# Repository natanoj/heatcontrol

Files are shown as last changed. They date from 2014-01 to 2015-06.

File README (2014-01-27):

This repository contains documentation in the form of schematics, pcb
design files and text documents describing the design, implementation
and testing of a system for home automation as well as software needed
to run on the hardware. The primary goal for the system is home heat
regulation, but it is not limited to that.

The fundamental requirements for this project is for communication to
be carried over IP, preferably IPv6, over Ethernet. See the
./doc/report for details.

System software will be based on the Contiki OS, see the submodule
./software/contiki

Design software used
====================
The goal is to only use open source software programs in this project.
The hardware design is created using software from the gEDA project,
see http://www.geda-project.org/ with electronic simulation using the
Gnucap simulator, see http://www.gnucap.org . Schematics are created
using gschem 1.6 and 1.8.

Directory structure
===================
./doc/report a report for the system, including design calculations
./schem      schematics
./pcb        PCB layouts
./software   software running on or communicates with the system

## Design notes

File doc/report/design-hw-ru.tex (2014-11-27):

% Copyright Jonatan Åkerlind 2012
% design process of the room unit

\subsubsection{Component selection}
The unit should present a few parameters to the user and also be able
to react on user input. For this requirement a simple LCD and a few
push buttons is sufficient. A simple two row LCD with integrated
driver, the Newhaven Display NHD-C0220BIZ-FS(RGB) with integrated RGB
backlight, is selected. For the push buttons debounce an MCU is
used. This MCU will also be used to drive the RGB backlight diodes
using PWM to control the color and brightness. The Atmel ATtiny24A is
chosen since it has three PWM output channels and enough I/O to
support the push buttons.

Communications by Ethernet need connector, magnetic components for
electrical isolation and an Ethernet interface circuit. The MAG45
Ethernet jack with integrated magnetic, LED and PoE diode components
is chosen to simplify design effort and minimize board size. For the
driver circuit the Micrel KSZ8851 is selected due to price and simple
SPI interface. For Power over Ethernet operations a DC-DC converter
transformer with a PWM driver and a PoE driver circuit is needed. The
Texas Instruments TPS23757 is selected as the driver circuit since it
has both PoE and DC-DC PWM converter driving interfaces. Würth
eletronics has several options for ready-made flyback DC-DC PWM
transformers with PoE level input, auxilary output for driving the PWM
circuit matching the TPS23757 and output options for wanted Vdd
voltage.

As environment sensors the Microchip TC1046 is chosen as the
temperature sensor due to price as well as being pre-calibrated. The
Honeywell HIH-5031 is chosen as the relative humidity sensor since it
has a very simple linear voltage output which will simplify the sensor
interface design process. An optional pyrolytic infrared (PIR) sensor
can be used to detect human presence in the room that is
regulated. The Zilog ZMOTION Detection Module II is chosen for
simplicity since the module is ready to use with a simple serial
interface and the relatively small form factor.

The Atmel ATmega1284P is chosen as the MCU since it has I/O that will
support SPI interface for the Ethernet controller and TWI interface
for the display and ATtiny24A, AD converters for temperature and
humidity sensors. Four interrupt inputs are used for pushbutton
events, ethernet data events, ethernet power management events (Wake
on LAN) and PIR signal events.

All resistors are chosen from the E48 series.

\subsubsection{Power budget}
Power budget for all components except the PSU components can be seen
in \tabref{tab:powerbudget_roomunit}. All components can or need to be
driven by 3.3 V which therefore is selected as the overall system
voltage, $V_{DD}$. The total maximum power budget for the design is
seen in the table as approximately 140 mA. For the power supply output
stage a maximum current of 250 mA and a minimum of 100 mA is chosen.

\begin{table}
\begin{tabular}{|l|l|l|l|}
\hline
Reference designator & Name        & Typical current & Max current\\
\hline
U100                 & TC1046      & 35 $\mu$A        & 60 $\mu$A\\
U101                 & HIH-5031    & 200 $\mu$A       & 500 $\mu$A\\
A100                 & ZDM II      & $<$ 8.9 mA          & 8.9 mA\\
U200                 & NHD-C0220BIZ-FS & 1 mA         & 1 mA ? \\
U200 (LED)           & NHD-C0220BIZ-FS(RGB) & $<$ 44 mA  & 44 mA \\
U201                 & ATtiny24A   & 210 $\mu$A       & 210 $\mu$A ? \\
U301                 & KSZ8851     & 85 mA            & 85 mA ? \\
U400                 & ATMega1284P & 0.4 mA           & 0.4 mA ? \\
D552                 & LGQ971      & 20 mA            & 20 mA \\
\hline
Total                &             & $<$ 160 mA            & 160 mA \\
\hline
\end{tabular}
\caption{Power budget for room unit 3.3 V components}
\label{tab:powerbudget_roomunit}
\end{table}

\subsubsection{PoE converter}
According to the power budget summary
in \tabref{tab:powerbudget_roomunit} and the previous section the
maximum power drawn is approximately 330 mW. This is without the power
consumed by the DC/DC converter itself (TPS23757). According to the
PoE standard there are different classifications based upon maximum
average power for a powered device. The lowest power class (Class 1)
specifies a minimum power of 440 mW and a maximum power of 3.84 W. If
the power consumption drops below the minimum the power source
equipment may turn the PoE off and this needs to be verified
carefully. The class is chosen by a classification resistor connected
to the TPS23757 (R501 in the schematics) and should be 243 $\Omega$
for Class 1.

The optional DC adapter interface uses a resistor devider network
(R505, R506) to get the proper voltage at the APD pin of the
TPS23757. This will be designed to be used with a 48 V DC $\pm$10 \%
adapter according to the examples given in Texas Instruments document
SLVA305A. R506 is chosen as 6.8 k$\Omega$ and the minimum startup
voltage is chosen 25 \% below 48 V
% FIXME: reference slva305a properly

\begin{equation}
Vin_{MIN}=48 * 0.75 = 36 \text{ V}
\end{equation}
The ratio between $Vin_{MIN}$ and adapter priority pin typical voltage,
$V_{APDEN}=1.5\text{V}$, is given by
\begin{equation}
DR_{APD}=\frac{Vin_{MIN}}{V_{APDEN}}=\frac{36 \text{ V}}{1.5 \text{ V}}=24
\end{equation}
From here the R505 can be calculated by
\begin{equation}
R505 = R506 * (DR_{APD} - 1) = 156.40 \text{ k$\Omega$}
\end{equation}
R505 is chosen as 158 k$\Omega$. Now the adapter turnon voltage
becomes
\begin{equation}
Vin_{MIN}=\frac{R505+R506}{R506} * V_{APDEN}
= \frac{164.8 \text{ k$\Omega$}}{6.8 \text{ k$\Omega$}} * 1.5 \text{ V}
= 36.353 \text{ V}
\end{equation}
and the adapter turnoff voltage, $V_{ADPTR\_OFF}$, is given by the
minimum adapter priority pin voltage ($V_{APDEN} - V_{APDH}$), where
$V_{APDH}$ is the hysteresis for the APD pin which is 0.31 V
typically.
\begin{equation}
V_{ADPTR\_OFF}=\frac{R505+R506}{R506} * (V_{APDEN} - V_{APDH})
= \frac{164.8 \text{ k$\Omega$}}{6.8 \text{ k$\Omega$}} * 1.2 \text{ V} =
29.082 \text{ V}
\end{equation}
The maximum voltage at the APD pin is, using a 48 V adapter with 10 \% error
\begin{equation}
V_{APD} < \frac{Vin_{MAX}}{\frac{R505+R506}{R506}}
= \frac{48*1.1 \text{ V}}{\frac{164.8 \text{ k$\Omega$}}{6.8 \text{ k$\Omega$}}}
= 2.179 \text{ V}
\end{equation}
which is less than $V_B$ (5 V) and so within the recommended maximum
voltage.

The flyback modulator power stage with feedback network is designed
according to the example given in SLV305A.
% FIXME: reference SLV305A
To minimize the transformer size Discontinous Conduction Mode is
used. With an assumed converter efficiency ($\eta$) of 85 \% and the
given DC voltage transfer ratios according to

\begin{equation}
V_{Imin}=36 \text{ V},
\end{equation}
\begin{equation}
V_{Imax}=57 \text{ V}
\end{equation}
Minimum DC voltage transfer function
\begin{equation}
M_{V DCmin}=\frac{V_O}{V_{Imax}}=\frac{3.3}{57}=0.057895
\end{equation}
and maximum DC voltage transfer function
\begin{equation}
M_{V DCmax}=\frac{V_O}{V_{Imin}}=\frac{3.3}{36}=0.091667
\end{equation}

and assumed duty cycle at DCM/CCM boundary $D_{b max}$=0.3 the minimum
input-output winding ratio of the transformer becomes

\begin{equation}
N_{ps min}=\eta \frac{D_{b max}}{(1-D_{b max})M_{V DCmax}}=3.97
\end{equation}

The PoE transformer (T550) with input (48 V), output (3.3 V and 5 V)
and auxilary (12 V) windings. Prebuilt transformer from TDK part
number EFD15 B82802A0012A315 is chosen, which has 100 $\mu$H input
inductance, 3 $\mu$H leakage inductance at 100 kHz and 1.5 $kV_{AC}$
breakdown between windings. The transformer is specified for input
voltages between 36 - 60 V DC and has a winding ratio (n) between
input and primary output windings of 10. Chosen switching frequency is
200 kHz, to program the TPS23757 to run at 200 kHz a resistor is
connected between the FRS and ARTN pins (R502) with a value given by
\begin{equation}
R502 = \frac{17250}{f_{SW} (kHz)} = \frac{17250}{200} \text{
k$\Omega$} = 86.25 \text{ k$\Omega$}
\end{equation}

A resistor with 86.6 k$\Omega$ resistance is chosen.

To keep the flyback in DCM the maximum magnetizing inductance is
\begin{equation}
L_{m max}=frac{N_{ps}^2 R_{l min} (1-D_{b max})^2}{2
f_{s}}=489 \text{$\mu$ H}
\end{equation}

Which is above the chosen transformer rating.

The switching transistor Q550 and the rectifying diode D551 will be
exposed to voltage and current stresses according the following
calculations.

Minimum and maximum duty cycles
\begin{equation}
D_{min}=M_{V DCmin} \sqrt{\frac{2 f_s L_m}{\eta R_{l min}}}=0.10931
\end{equation}
\begin{equation}
D_{max}=M_{V DCmax} \sqrt{\frac{2 f_s L_m}{\eta R_{l min}}}=0.17308
\end{equation}

%% only for CCM(?)
The peak-to-peak ac current through the magnetizing inductance (input) is
\begin{equation}
\Delta i_{Lm(max)}=\frac{nV_O (1-D_{min})}{f_s L_m}
= \frac{10*3.3*(1-0.10931)}{2*10^5*100*10^{-6}} \text{ A} = 1.4696 \text{ A}
\end{equation}

The current and voltage stresses of the switching transistor and the
rectifying diode are given by
\begin{equation}
I_{SMmax} = \frac{D_{min}V_{Imax}}{f_s L_m} = \frac{0.109*57}{200*10^3*100*10^{-6}} \text{
A} = 0.31154 \text{ A}
\end{equation}
\begin{equation}
I_{DMmax} = nI_{SMmax} = 10*0.31154 \text{ A} = 3.1154 \text{ A}
\end{equation}
\begin{equation}
V_{SMmax} = V_{Imax} +nV_O = 57 + 10*3.3 \text{ V} = 90 \text{ V}
\end{equation}
\begin{equation}
V_{DMmax} = \frac{V_{Imax}}{n} + V_O = \frac{57}{10} + 3.3 \text{ V}
= 9 \text{ V}
\end{equation}
The N-MOSFET IRLM0100TRPbF from International Rectifier can handle
$V_{DSS}=100$ V and $I_D=1.6$ A with a maximum $R_{DS(on)}$ of 220
m$\Omega$ at $V_{GS}=10$ V. Typical gate charge $Q_g=2.5$ nC and
output capacitance $C_O=27$ pF. Multicomp SS54 Schottky diode has a
maximum $I_{DM}=5$ A, maximum reverse voltage $V_{DM}=40$ V and
forward voltage drop $V_F=0.55$ V at 5 A which gives an equivalent
resistance $R_F$ of 0.11 $\Omega$.

Adjusted peak voltage at switching transistor due to transformer leakage
inductance $L_l$, primary $R_p$ and secondary $R_s$ winding
resistances, stray input capacitance $C_p$, and transistor output
capacitance $C_O$. Ringing frequency
\begin{equation}
f_{ring}=\frac{\omega_{ring}}{2\pi}=\frac{1}{\sqrt{L_l(C_O+C_p)}}
\frac{1}{2\pi}=15.106 \text{ MHz}
\end{equation}
characteristic impedance of ringing circuit
\begin{equation}
Z_0=\sqrt{\frac{L_l}{C_O+C_p}}=284.75 \Omega
\end{equation}
ringing voltage spike
\begin{equation}
V_{spike}=I_{SMmax}Z_0=88.711 \text{ V}
\end{equation}
adjusted switching voltage stress
\begin{equation}
V_{SMmax adj}=V_{Imax}+nV_O+V_{spike}=178.71 \text{ V}
\end{equation}
This will be limited with snubber circuit $D_{sn}$ (D553), $R_{sn}$
(R558), and $C_{sn}$ (C555) with $V_{spike new}$ as 5 V.
\begin{equation}
C_{sn(min)}=(\frac{V_{spike}}{V_{spike
new}})^2(C_O+C_p)=11.647 \text{ nF}
\end{equation}
Choosing $C_{sn}$ as 15 nF. Choose $R_{sn}$ for time constant much
larger than switching frequency
\begin{equation}
R_{sn}=\frac{200}{f_s C_{sn}}=66.667 \text{ k$\Omega$}
\end{equation}
Choosing $R_{sn}$ as 64.9 k$\Omega$.
For $D_{sn}$ the MURA120 from ON Semiconductor is chosen, with peak
reverse voltage $V_R$ 200 V and average forward current $I_F$ 1 A.

Maximum input voltage ripple targeted below 1 V gives minimum filter
capacitance
\begin{equation}
C_{in(min)}=\frac{\Delta i_{Lm(max)}D_{max}}{f_s V_{Iripple}}=
1.2718 \mu F
\end{equation}
Choosing $C_{in}$ as one low ESR X7R MLCC 2.2 $\mu$F (C556) and one bulk aluminum
electrolytic at 2.2 $\mu$F (C550).

For the current sense input to the control circuit a resistor,
$R_{CS}$ (R551), is chosen from the primary winding peak current and
max input voltage on $V_{CS}$. According to the datasheet $V_{CSMAX}$
= 0.55 V.

\begin{equation}
R_{cs_{MIN}} = \frac{V_{CSMAX}}{I_{SMmax}} = \frac{0.55}{0.327} =
1.682 \text{$\Omega$}
\end{equation}
$R_{CS}$ is chosen as 1.8 $\Omega$. Maximum power dissipation for this
would then be approx 0.19 W if the peak current was constant. This
corner case is highly unlikely but dimensioning for this case will
keep the design on the safe side. An SMD resistor rated for 250 mW is
chosen.

Output voltage ripple should be below 2 \%
\begin{equation}
V_r=0.02V_O = 0.02*3.3 \text{ V} = 66 \text{ mV}
\end{equation}

% with only one filter capacitor
Equivalent minimum load resistance
\begin{equation}
R_{Lmin}=\frac{V_O}{I_{Omax}} = \frac{3.3}{0.25} \text{ $\Omega$} =
13.2 \text{ $\Omega$}
\end{equation}

Assuming ripple voltage over filter capacitor ESR $V_{rcpp}=27$ mV and
the rest over the filter capacitance $V_{Cpp}=6$ mV gives the maximum
ESR of the filter capacitor
\begin{equation}
r_{Cmax} = \frac{V_{rcpp}}{I_{DMmax}} =
\frac{27}{4.089} \text{ m$\Omega$} = 6.6 \text{ m$\Omega$}
\end{equation}
and the filter capacitance
\begin{equation}
C_{min} = \frac{D_{max}V_O}{f_sR_{Lmin}V_{Cpp}} \text{ F} =
\frac{0.589*3.3}{3*10^5*13.2*6*10^{-3}} = 81.8 \text{ $\mu$F}
\end{equation}

Output voltage set point resistors are calculated using the estimated
integrator zero location at approximately 1 kHz. Integrator zero
capacitors range between 1 nF - 10 nF, 4.7 nF is assumed.
\begin{equation}
R_{IZE} \approx \frac{1}{2* \pi * 4.7 nF * 1 kHz} =
33.9 \text{k$\Omega$}
\end{equation}
\begin{equation}
R_{FBUE} \approx R_{IZE}
\end{equation}
$R_{FBU}$ (R553) chosen as 41.2 \text{k$\Omega$}. $V_{ref}$ = 1.24 V
which then gives $R_{FBL}$ (R554)
\begin{equation}
R_{FBL} = \frac{V_{ref}*R_{FBU}}{V_{out_{NOM}} - V_{ref}}
= \frac{1.24*41.2}{3.3-1.24} = 24.8 \text{k$\Omega$}
\end{equation}
$R_{FBL}$ chosen at 24.3 \text{k$\Omega$} which gives a slightly
higher nominal output voltage. This will compensate a small voltage drop
in the output circuit.

Opto-Isolator, U550, should have a current-transfer-ratio of about
80-160 \% at 5 mA. The Fairchild FOD817A is chosen. At 1-2 mA LED bias
current it has an approximate current-transfer-ratio of 85 \%. Forward
LED voltage $V_{led_{OPTO}}$ at 2 mA is approximately 1.1 V. Bias
current limiting resistor, $R_{OB}$ (R552) calculated at zero duty
cycle
\begin{equation}
V_{led{OPTO_K}} = V_{ref} + 150 mV
\end{equation}
\begin{equation}
R_{OB} = \frac{V_{out_{NOM}} - V_{led_{OPTO}} -
V_{led_{OPTO-K}}}{I_{led_{OPTO}}} = \frac{3.3 - 1.1 - 1.25}{2*10^{-3}}
= 475 \Omega
\end{equation}
The opto-isolator transistor bias current calculated at zero duty
cycle (values from the datasheet of TPS23757). $V_{zdc_{MAX}}$ = 1.7
V, $V_{cs_{MAX}}$ = 0.55 V at $V_B$ = 5 V.
\begin{equation}
V_{ctl_{MAX}} = V_{zdc_{MAX}} + 2*V_{cs_{MAX}}
\end{equation}
\begin{equation}
V_{ctl_{NOM}} = \frac{V_{zdc_{max}} + V_{ctl_{MAX}}}{2} = 2.25 V
\end{equation}
\begin{equation}
R_{CTL} = \frac{V_b - V_{zdc_{MAX}}}{I_{led_{OPTO}}*CTR_{2mA}} =
1.9412 \text{k$\Omega$}
\end{equation}
$R_{CTL}$ (R550) chosen as 2 \text{k$\Omega$}.

% FIXME: do we need secondary side soft start according to SLVA305C 2.8.6 ?

\subsubsection{Peripheral components}
The display needs two capacitors to drive the internal boost converter
for 5 V supply, these are 1 $\mu$F each. The backlight LEDs are
specified according to \tabref{tab:backlightleds} and need serial
resistors with values according to \ref{eq:rledred}, \ref{eq:rledgreen}
and \ref{eq:rledblue}.
\begin{equation}
R_{Red} = \frac{3.3 - 1.9}{17} \text{ k$\Omega$} = 82 \text{ $\Omega$}
\label{eq:rledred}
\end{equation}
\begin{equation}
R_{Green} = \frac{3.3 - 3.0}{17} \text{ k$\Omega$} = 18 \text{ $\Omega$}
\label{eq:rledgreen}
\end{equation}
\begin{equation}
R_{Blue} = \frac{3.3 - 3.0}{10} \text{ k$\Omega$} = 30 \text{ $\Omega$}
\label{eq:rledblue}
\end{equation}

A number of digital nets need pull-up or pull-down resistors, to
minimize leakage currents a typical value of 100 k$\Omega$ is
used. This will only draw 33 $\mu$A when the line is being driven. To
keep external components around the microcontrollers at a minimum the
internal pull-ups are enabled for unused pins and these are left
unconnected. This has the drawback of higher power consumption during
reset condition, but this only occurs either when programming the
microcontroller program memories or when a user presses the reset
button. The latter should however be seen as an exception and will
probably only be used during software development or hardware
verification.

\begin{table}
\begin{tabular}{|l|l|l|}
\hline
Colour & Voltage drop (V) & Current (mA)\\
\hline
Red & 1.9 & 17\\
Green & 3.0 & 17\\
Blue & 3.0 & 10\\
\hline
\end{tabular}
\caption{LCD Backlight LED drive voltages and currents}
\label{tab:backlightleds}
\end{table}

\subsubsection{Mechanical aspects}
The PCBs need to fit in the housing with display, buttons, and PIR
sensor at the proper height. The chosen buttons, Multicomp MCDTS2-4N
12 mm, are 4.3 mm from bottom edge (mounted to PCB) to the button
level. Switch caps, Multicomp KTSC-22, are in total 7.7 mm in height
with a stop surface at 3.5 mm from the bottom. This means that the
casing front inner plane should be at least $4.3+3.5=7.8$ mm from the
top layer of the PCB. The caps have a rounded outer edge at the top
with 1 mm radius and travelling length of 0.5 mm. Assuming a casing
thickness of 2 mm, the casing front inner plane can be at most
$4.3+7.7-1-0.5-2=8.5$ mm from the top layer of the PCB.

The PIR sensor, Panasonic PaPIR EKMC1603113, is in total 20.2 mm from
bottom edge (mounted to PCB) to the top of the lens. The lens is
approximately a half sphere with diameter 22 mm, but edges cut down to
a cylindar with 20.7 mm diameter for mounting in casing. The height
from top of the sphere to the cut edge is given by the circle segment
\begin{equation}
h(2r-h)=\left(\frac{x}{2}\right)^2
\end{equation}
where h is the wanted height, r the radius of the sphere, and x the
segment length. The resulting height is
\begin{equation}
h=\frac{2r}{2}\pm\sqrt{\left(-\frac{2r}{2}\right)^2-\left(\frac{x}{2}\right)^2}=
\begin{cases}
14.725 & >r ~\text{not wanted solution},\\
7.2747 & <r ~\text{wanted solution}.
\end{cases}
\end{equation}

The PIR sensor casing has an edge at 7.3+2 mm from the bottom, which
represents the lowest possible height from top of PCB to inner edge of
casing front.

Combining these dimensions the PIR sensor and the push buttons can be
directly mounted to the PCB with a 2 mm thick casing front at 9.3 mm
from the PCB to inner edge of casing. With the push buttons mounted
closely to the PCB the caps will only protrude $\approx 0.7$ mm,
however the push buttons have 3.5 mm long leads and can therefore be
mounted with a $\approx 1$ mm distance to the PCB surface placing the
switch cap tops at $\approx 1.7$ mm above the casing outer surface.

The EA DOG-M display is 2 mm thick with 7.5 mm long leads at the
bottom for a total length of 9.5 mm from the top surface to the lead
ends. This means that the display needs to be mounted with some
special care. A separate board to mount the display and related
passives and cutting the display leads down to 2.5 mm would leave
approximately $9.3-2-2.5=4.8$ mm between top of PCB to display lead
ends.

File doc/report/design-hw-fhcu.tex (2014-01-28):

% Copyright Jonatan Åkerlind 2012
% design process of the floor heating control unit
Floor heating control unit

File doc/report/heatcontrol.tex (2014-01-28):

\documentclass[a4paper,11pt]{article}
% Copyright Jonatan Åkerlind 2012

% language and character encoding
\usepackage[english]{babel} \usepackage[utf8x]{inputenc}

% nice looking urls
\usepackage{url} \urlstyle{same}

%include eps
\usepackage{graphicx}

% nice code formatting and file referencing
\usepackage{moreverb}

% many nice math functions
\usepackage{amsmath}

% clickable pdf links without borders
\usepackage[pdfborder= 0 0 0]{hyperref}

% needed to access footnote counter for working around
% problems with foontotes in table environments
\usepackage{fmtcount}

% easier referencing of figures, tables and appendices
\newcommand{\figref}[1]{\figurename~\ref{#1}}
\newcommand{\tabref}[1]{\tablename~\ref{#1}}
\newcommand{\appref}[1]{Appendix~\ref{#1}}

\title{Heatcontrol} \author{Jonatan Åkerlind}

\begin{document}

% insert title
\maketitle
\thispagestyle{empty}

\newpage
\begin{abstract}
\setcounter{page}{1}
\noindent{This document describes the specification, planning,
  designing, building and testing of an electronic domestic heat
  control system. The system regulates the temperature in rooms in a
  house by measuring room and outdoor temperature and regulating
  temperature of water based convector heaters as well as water based
  floor heating.}

\end{abstract}

%\thispagestyle{empty}
\newpage

% Table of contents
\tableofcontents

%\thispagestyle{empty}
\newpage

\section{Introduction}
\input{introduction}

\clearpage
\newpage
\section{Specification}
\input{specification}

\clearpage
\newpage
\section{Design}
\input{design}

\clearpage
\newpage
\section{Design verification}
\input{design-verification}

\clearpage
\newpage
\section{Manufacturing}
\input{manufacturing}

\clearpage
\newpage
\section{Product verification}
\input{product-verification}

\clearpage
\newpage
\section{Conclusions}
\input{conclusions}

\clearpage
\newpage
\input{references}

\clearpage
\newpage
%\input{appendix}

\end{document}

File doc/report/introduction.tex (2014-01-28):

% Copyright Jonatan Åkerlind 2012
This document will describe the design and implementation of a heat
control system for water based domestic heating applications.

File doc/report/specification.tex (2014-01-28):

% -*- Mode: latex; Mode: auto-fill -*-
% Copyright Jonatan Åkerlind 2012
The system should regulate the temperature of rooms in a house to
maintain a preset temperature and at the same time be conservative
with available energy. Temperature preset should be adjustable for
each room in a simple way from the rooms. Further the system should
have a way to set different temperatures during different time ranges
of one day, i.e. to lower the room temperature during night or when
the room is unused.

Another functionality of the system should be the ability of measuring
warm water temperature and controlling warm water circulation. The
temperature should be measured where the warm water circulation end
point is located, i.e. in the house which warm water is delivered
to. When this temperature drops below some preset value the warm water
circulation pump should be activated and run until the temperature
reaches the stored warm water temperature with heat losses calculated
for. 

\subsection{Regulating room temperature}
Room temperature can be controlled by adjusting
heat flow in a water based heating system. Each room will have either
water radiator elements or water based floor heating. The temperature
of the water system can be controlled in a number of ways:
\begin{itemize}
\item{Adjusting the temperature of water flowing in to the radiators
  and floor heating. These two systems can have individual water
  temperatures\footnote{The temperature of the floor heating water
    cannot exceed the temperature of the water radiators since the
    shunt for the floor heating takes warm water from the radiator
    heat water forward pipe} controlled by motorized shunt
  valves\footnote{The motorized shunt valves will have end limit
    switches, normally open non-potential contacts, indicating max or
    min setting}.}
\item{Controlling water flow in the floor heating system for each
  room. Water flow is controlled by electromagnetic valves which are
  either on or off.}
\item{Controlling water flow in the radiators for each room by turning
  an electromagnetic valve on or off. For systems with thermostats already
  installed there should be an option of indicating to the user if the
  thermostat should be adjusted up or down, i.e. an indirect way of
  controlling water flow in the radiators.}
\item{Circulation pumps for the two different water flows can be
  turned off when the system no longer needs to add heat and likewise
  turned on again for supplying heat.}
\end{itemize}

Heat supply for the system is stored in water accumulators charged by
a system outside the scope of this system, however it should not be
assumed that heat is always available in the accumulators. To reliably
regulate supplied temperature to the water circulation the temperature
of water stored in the accumulators should be measured. 

Input parameters for the regulation needs to be a number of
parameters:
\begin{itemize}
\item{Room temperature for each room.}
\item{Water radiator and floor heating forward and
  return\footnote{The return water temperature can be used to
    calculate total power dissipation for the system.} temperatures.}
\item{Heat water accumulator top and bottom temperatures. This is for
  measuring available energy.}
\item{Outdoor temperature should be used to compensate for energy
  leakage rising with lower outdoor temperatures.}
\end{itemize}
Additionally the system should measure relative air humidity both
outdoor and for each room. This should then be used to both add a
comfort factor, i.e. optionally raise the temperature if it is cold
and humid outside, as well as protect cold rooms from being too
humid. 

\subsection{Heat system interaction}
The interaction with a heater system is to be located at several
different physical locations. One is where the water accumulators are
located, i.e. the energy supply and storage which typically will be a
furnace, solar heater or some kind of heat pump which charges water
accumulators. Another interface is at one or several places where
floor heat water flow is controlled. Both of these types should have
the possibility to control electric shunting valves but only the
latter needs to control regular electric valves.

Regulating electric shunting valves includes checking that the valve
has not reached its end limit in the direction it is being turned. It
also includes measuring the temperature of the regulated water pipe,
which should be measured closely to the shunting valve, as well as the
return water temperature. The unit placed at the location of the water
accumulators needs to be able to measure one outdoor temperature, four
pipe temperatures (water radiator forward and return, accumulator top
and bottom temperatures) and one outdoor air relative humidity. It
also needs to be able to control two circulation pumps, one for warm
water circulation and one for heat water circulation. This heat water
circulation is to be considered a general purpose pump that can be
either heat water circulation over to the house that is to be heated
if the water accumulators are located at another location outside of
the house, or it can be circulation for a separate heater system. In
the first case it should be activated if either of the other
circulation pumps (floor heating or water radiator) are running and in
the second case it should be activated if a room unit for this
separate system requires more heat. In either case it is to be
considered optional.

Floor heating control unit needs to be able to control floor heating
electromagnetic valves for 12 rooms as well as two circulation pumps,
one for the water radiator circulation and one for floor heat
circulation. It should also be able to measure one air temperature and
one air relative humidity as well as the warm water pipe temperature
at the end point of the warm water circulation.

The system should have a standby mode when it should not apply heat
but keep the circulation pumps running for one hour each month. The
shunt valves should also be turned one complete turn from low to high
once each month. This is to keep the pumps and shunt valves from
jamming when the system is unused for a long period of time. All
electromagnetic valves should also be toggled once each month for the
same reason.

\subsection{System interfaces}
Human interaction with the system should be possible in a number of
different ways. In each room the system should display, without the
need to press any buttons or other manual interaction, current room
temperature, wanted room temperature, outdoor temperature and the
current day/night setting. In each room it should also be possible to
see the current room and outdoor relative humidity, however this may
require some manual interaction from the user. The wanted room
temperature as well as day/night setting for that room should be
adjustable from each room in a simple way. Day versus night setting
should be selectable as one of the following; follow the system time
schedule, override as day or night until time schedule changes next
time or override as day or night until user selects another
setting. If using the option of controlling water radiators indirectly
the system must indicate if water radiator thermostats should be
adjusted up or down. The room units controlling floor heating should
also indicate if heat is applied to the room or not.

The unit placed at the location of the water accumulators (the main
unit) should indicate if each output is on or off, if each shunt valve
is regulated up, down or kept at its current setting and display each
input value. It should also show current system day/night setting and
be able to show the day/night time schedule. All system parameters
except individual room temperatures should also be adjustable from
this unit. These are the specified system parameters:
\begin{itemize}
\item{Parameters for the regulation of the forward heat water
  temperatures, i.e. the dependency on outdoor and indoor
  temperatures, outdoor and indoor relative air humidity or manually
  raising or lowering the forward heat water temperature}
\item{Circulation pumps on or off}
\item{Current day or night setting}
\item{Time schedule for day or night setting} 
\item{Warm water circulation high and low temperatures}
\item{System on or standby}
\end{itemize}

Time schedule for day or night setting should have a granularity of 15
minutes, i.e. it should be possible to set a new day or night setting
once every 15 minutes. A finer granularity than this should not be
necessary since the system as a whole is slow; it takes some time to
effectuate a new temperature in a house. 

Floor heat controlling unit should indicate if each output is on or
off, indicate if each shunt valve is regulated up, down or kept at its
current setting and display each input value. It should also show
current system day/night setting. 

There should also be web access to the main unit, i.e. the main unit
should serve HTTP
%% FIXME: reference RFC for HTTP
requests, which should display all system parameters and current input
values. It should also be possible to change the system parameters by
using this HTTP access. Parameters and input values should be
presented in a way that will make it easy to read these parameters
from some other computer system for logging purposes. Optionally the
main unit should have an SNMP
%% FIXME: reference RFC for SNMP
server that will show all parameters and input values and also enable
setting of parameters. Preferably the system should also have an
option to log all or a selection of events to a syslog
%% FIXME: reference RFC for syslog
server.

\subsection{Unit communication}
Communication between the room units and the other units of the system
is to be carried over Internet protocol version 6 (IPv6) or version 4
(IPv4)
%% FIXME: reference RFCs for IPv4 and IPv6
, version should be configurable by the user. IP communication
will be carried over Ethernet
%% FIXME: reference IEEE802.3 for Ethernet
and power supply for the room units
should be Power over Ethernet (PoE)
%% FIXME: reference IEEE802.3af for PoE
. This will then enable the room
units to use a pre-installed Ethernet network in the house that is to
be regulated. Optionally the room units should have power input for
external power supply in case PoE is not available.

Main unit will naturally act as a common communication central for all
other units. All parameters should be sent to the main unit and stored
there in a way that will keep them even if power fails.

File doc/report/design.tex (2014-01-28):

% Copyright Jonatan Åkerlind 2012
The system will consist of hardware, embedded software and optional
software running on a separate computer system for adjusting
parameters and monitoring the system. Each part of the system design
will be described in the following sections.

Design of the hardware components of the system is separated into
different pieces to reduce complexity in the design process. The
following pieces are designed seperately: main control unit, floor
heating control unit and room unit.

\subsection{Hardware: main control unit}
\input{design-hw-mcu}

\subsection{Hardware: floor heating control unit}
\input{design-hw-fhcu}

\subsection{Hardware: room unit}
\input{design-hw-ru}

\subsection{Embedded software}
\input{design-emb-sw}

\subsection{Operator software}
\input{design-oper-sw}

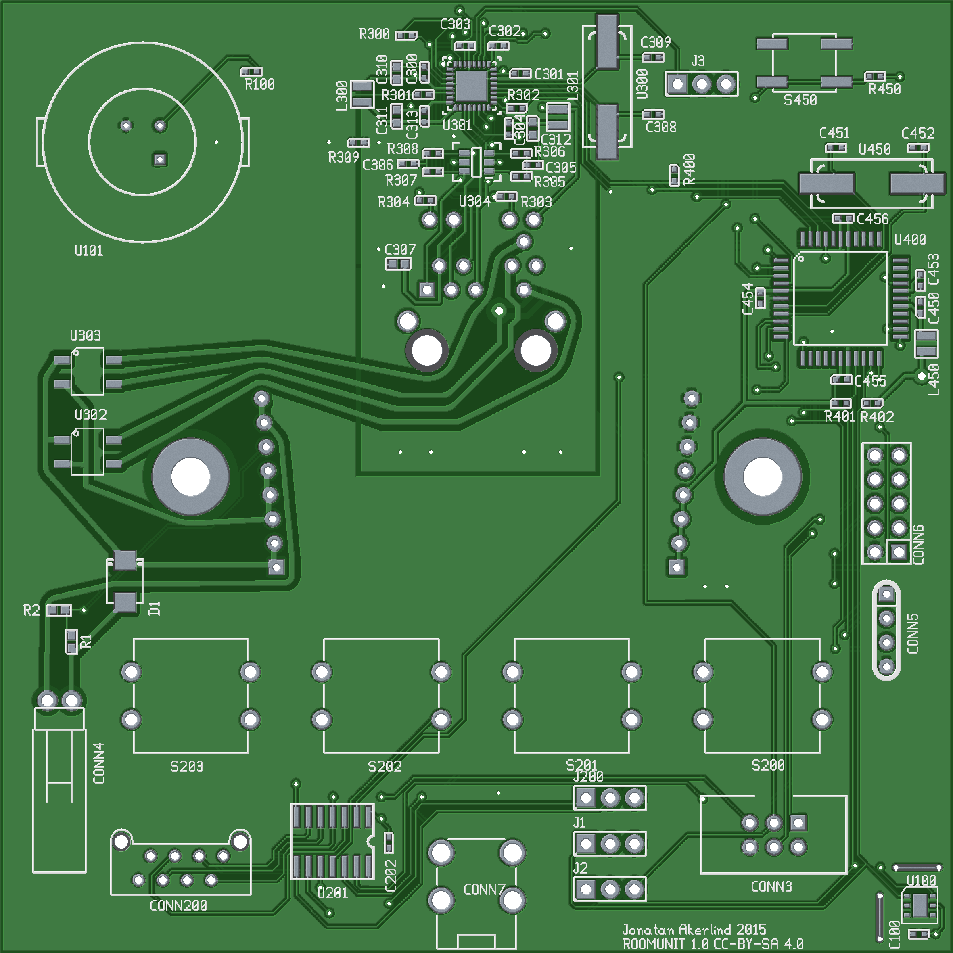
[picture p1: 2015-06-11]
pcb/roomunit.top.png

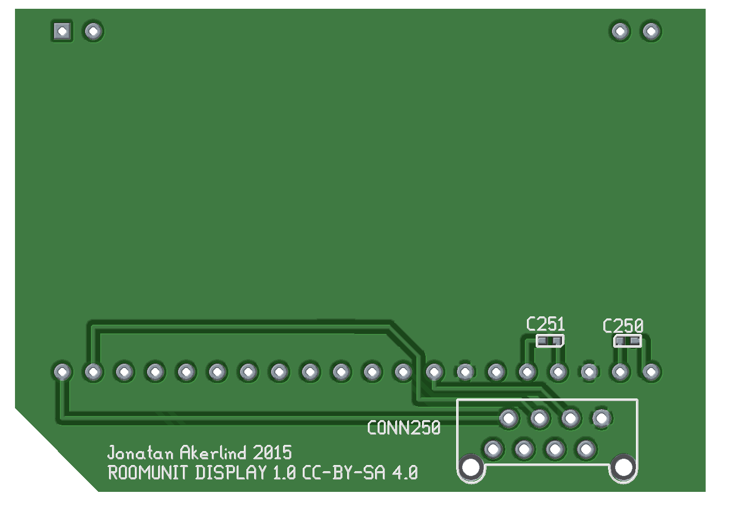
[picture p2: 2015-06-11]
pcb/roomunit-display.top.png

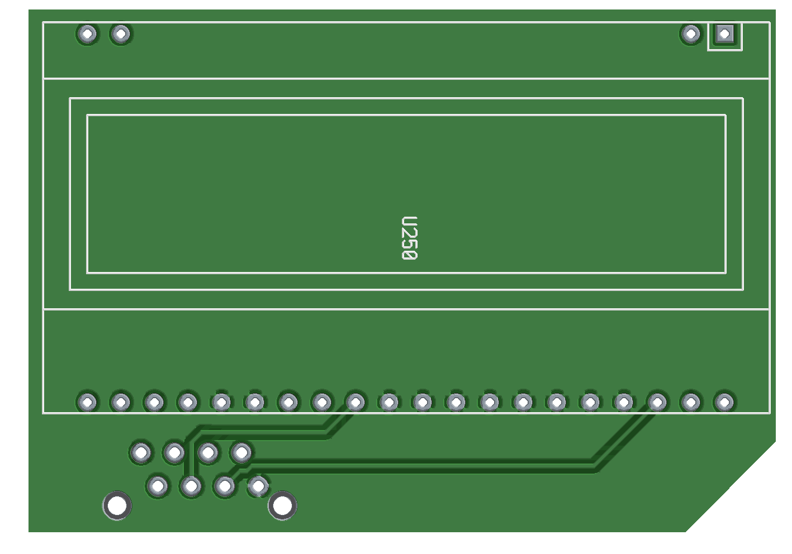
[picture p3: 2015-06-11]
pcb/roomunit-display.bottom.png

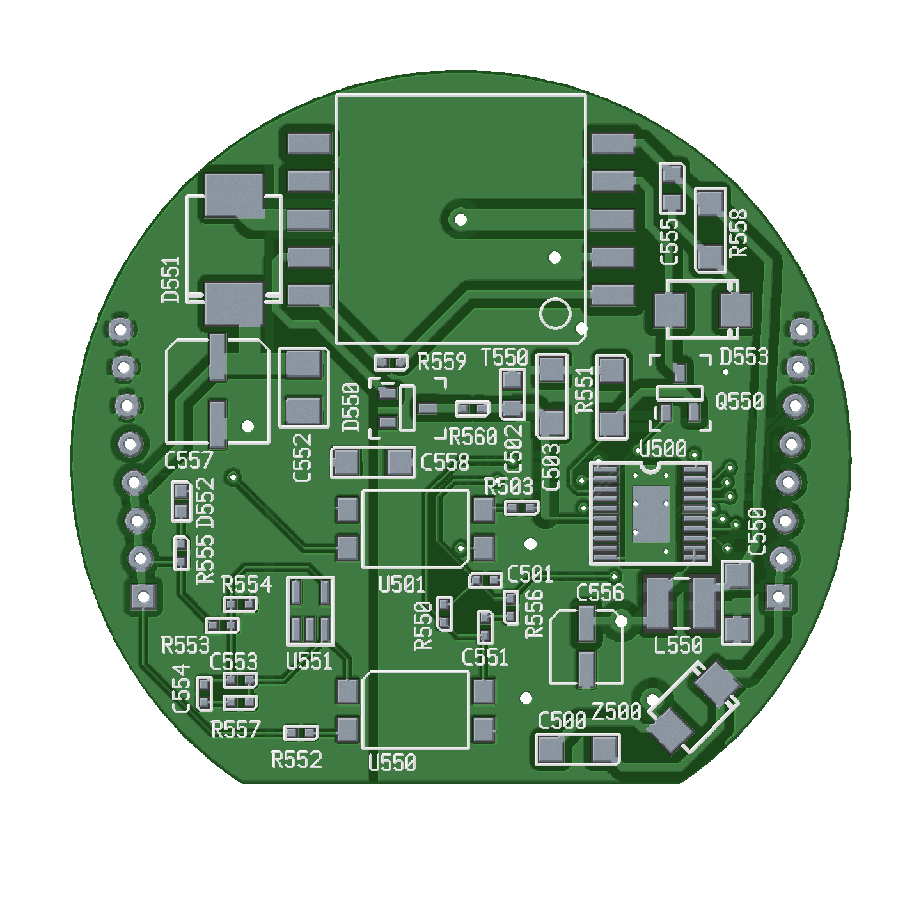
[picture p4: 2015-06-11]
pcb/roomunit-psu.top.png

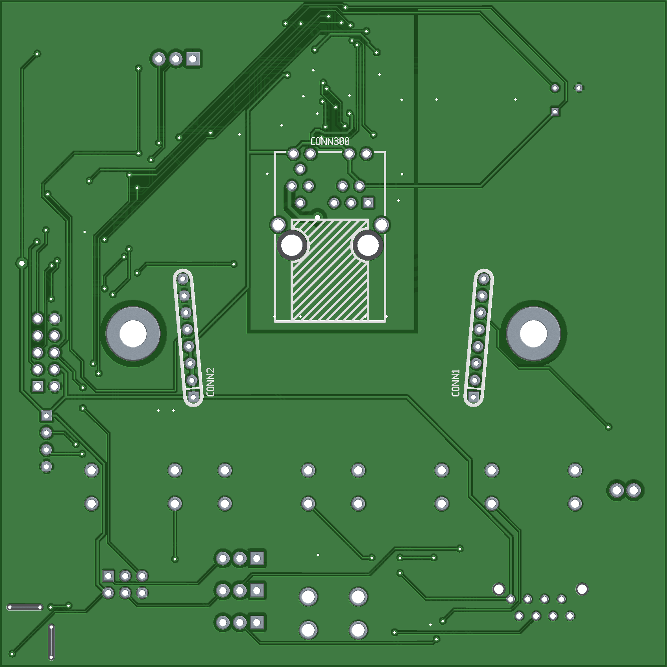
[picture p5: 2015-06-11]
pcb/roomunit.bottom.png

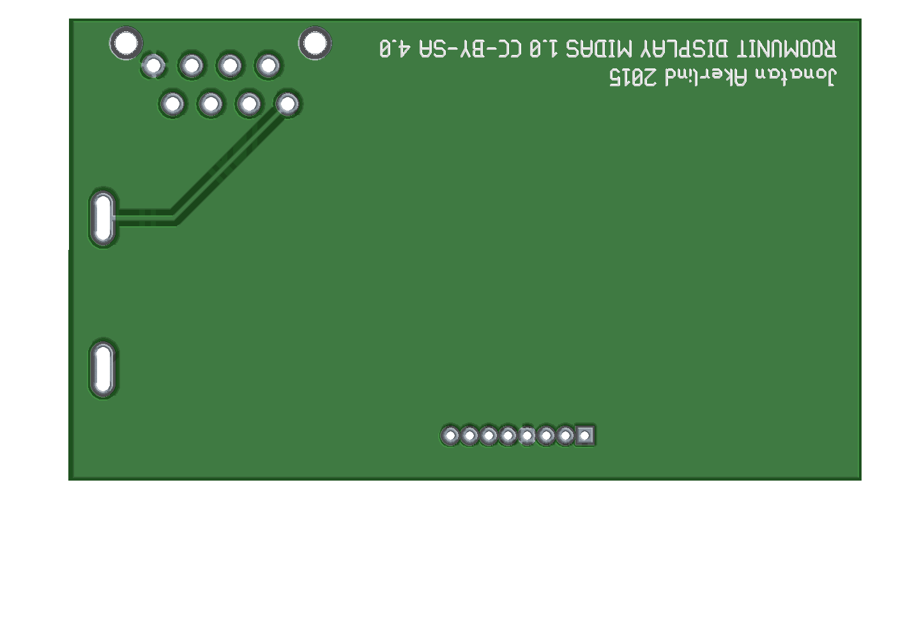
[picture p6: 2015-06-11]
pcb/roomunit-display-midas.bottom.png

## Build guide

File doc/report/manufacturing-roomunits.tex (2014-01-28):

% Copyright Jonatan Åkerlind 2012
Room sensors.

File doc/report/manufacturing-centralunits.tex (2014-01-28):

% Copyright Jonatan Åkerlind 2012
Central processing and controlling units.

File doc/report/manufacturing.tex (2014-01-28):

% Copyright Jonatan Åkerlind 2012
Manufacturing of the hardware.

\subsection{Room units}
\input{manufacturing-roomunits}

\subsection{Central units}
\input{manufacturing-centralunits}

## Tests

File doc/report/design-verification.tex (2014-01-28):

% Copyright Jonatan Åkerlind 2012
Each part of the system needs to be sufficiently verified before
manufacturing to ensure that no major bugs exist. Verification for
each part of the system will be described in the following sections.

\subsection{Hardware verification}
\input{design-ver-hw}

\subsection{Embedded software verification}
\input{design-ver-emb-sw}

\subsection{Operator software verification}
\input{design-ver-oper-sw}

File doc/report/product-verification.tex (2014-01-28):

% Copyright Jonatan Åkerlind 2012
Verification of the manufactured product.

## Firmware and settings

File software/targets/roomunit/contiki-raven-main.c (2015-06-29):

/*
 * Copyright (c) 2006, Technical University of Munich
 * All rights reserved.
 *
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
 * This file is part of the Contiki operating system.
 *
 * @(#)$$
 */
#define PRINTF(FORMAT,args...) printf_P(PSTR(FORMAT),##args)

#define ANNOUNCE_BOOT 1    //adds about 600 bytes to program size
#if ANNOUNCE_BOOT
#define PRINTA(FORMAT,args...) printf_P(PSTR(FORMAT),##args)
#else
#define PRINTA(...)
#endif

#define DEBUG 0
#if DEBUG
#define PRINTD(FORMAT,args...) printf_P(PSTR(FORMAT),##args)
#else
#define PRINTD(...)
#endif

/* Track interrupt flow through mac, rdc and radio driver */
//#define DEBUGFLOWSIZE 64
#if DEBUGFLOWSIZE
unsigned char debugflowsize,debugflow[DEBUGFLOWSIZE];
#define DEBUGFLOW(c) if (debugflowsize<(DEBUGFLOWSIZE-1)) debugflow[debugflowsize++]=c
#else
#define DEBUGFLOW(c)
#endif

#include <avr/pgmspace.h>
#include <avr/fuse.h>
#include <avr/eeprom.h>
#include <stdio.h>
#include <string.h>
#include <dev/watchdog.h>

#include "loader/symbols-def.h"
#include "loader/symtab.h"

#if RF230BB        //radio driver using contiki core mac
#include "radio/rf230bb/rf230bb.h"
#include "net/mac/frame802154.h"
#include "net/mac/framer-802154.h"
#include "net/sicslowpan.h"

#else                 //radio driver using Atmel/Cisco 802.15.4'ish MAC
#include <stdbool.h>
#include "mac.h"
#include "sicslowmac.h"
#include "sicslowpan.h"
#include "ieee-15-4-manager.h"
#endif /*RF230BB*/

#include "contiki.h"
#include "contiki-net.h"
#include "contiki-lib.h"

#include "dev/rs232.h"
#include "dev/serial-line.h"
#include "dev/slip.h"

#ifdef RAVEN_LCD_INTERFACE
#include "raven-lcd.h"
#endif

#if AVR_WEBSERVER
#include "httpd-fs.h"
#include "httpd-cgi.h"
#endif

#ifdef COFFEE_FILES
#include "cfs/cfs.h"
#include "cfs/cfs-coffee.h"
#endif

#if UIP_CONF_ROUTER&&0
#include "net/routing/rimeroute.h"
#include "net/rime/rime-udp.h"
#endif

#include "net/rime.h"

#include "params.h"

/* Get periodic prints from idle loop, from clock seconds or rtimer interrupts */
/* Use of rtimer will conflict with other rtimer interrupts such as contikimac radio cycling */
/* STAMPS will print ENERGEST outputs if that is enabled. */
#define PERIODICPRINTS 1
#if PERIODICPRINTS
//#define PINGS 64
#define ROUTES 600
#define STAMPS 60
#define STACKMONITOR 600
uint32_t clocktime;
#define TESTRTIMER 0
#if TESTRTIMER
uint8_t rtimerflag=1;
struct rtimer rt;
void rtimercycle(void) {rtimerflag=1;}
#endif
#endif

/*-------------------------------------------------------------------------*/
/*----------------------Configuration of the .elf file---------------------*/
#if 1
/* The proper way to set the signature is */
#include <avr/signature.h>
#else
/* Older avr-gcc's may not define the needed SIGNATURE bytes. Do it manually if you get an error */
typedef struct {const unsigned char B2;const unsigned char B1;const unsigned char B0;} __signature_t;
#define SIGNATURE __signature_t __signature __attribute__((section (".signature")))
SIGNATURE = {
  .B2 = 0x05,//SIGNATURE_2, //ATMEGA1284p
  .B1 = 0x97,//SIGNATURE_1, //128KB flash
  .B0 = 0x1E,//SIGNATURE_0, //Atmel
};
#endif

#if !MCU_CONF_LOW_WEAR
/* JTAG, SPI enabled, Internal RC osc, Boot flash size 4K, 6CK+65msec delay, brownout disabled */
FUSES ={.low = 0xe2, .high = 0x99, .extended = 0xff,};
#endif

/* Get a pseudo random number using the ADC */
uint8_t
rng_get_uint8(void) {
uint8_t i,j;
  ADCSRA=1<<ADEN;             //Enable ADC, not free running, interrupt disabled, fastest clock
  for (i=0,j=0;i<4;i++) {
    ADMUX = 0;                //toggle reference to increase noise
    ADMUX =0x1E;              //Select AREF as reference, measure 1.1 volt bandgap reference.
    ADCSRA|=1<<ADSC;          //Start conversion
    while (ADCSRA&(1<<ADSC)); //Wait till done
	j = (j<<2) + ADC;
  }
  ADCSRA=0;                   //Disable ADC
  PRINTD("rng issues %d\n",j);
  return j;
}

/*-------------------------Low level initialization------------------------*/
/*------Done in a subroutine to keep main routine stack usage small--------*/
void initialize(void)
{
  watchdog_init();
  watchdog_start();

#ifdef RAVEN_LCD_INTERFACE
  /* First rs232 port for Raven 3290 port */
  rs232_init(RS232_PORT_0, USART_BAUD_38400,USART_PARITY_NONE | USART_STOP_BITS_1 | USART_DATA_BITS_8);
  /* Set input handler for 3290 port */
  rs232_set_input(0,raven_lcd_serial_input);
#else
  /* Generic or slip connection on uart0 */
  rs232_init(RS232_PORT_0, USART_BAUD_38400,USART_PARITY_NONE | USART_STOP_BITS_1 | USART_DATA_BITS_8);
#endif

  /* Second rs232 port for debugging or slip alternative */
  rs232_init(RS232_PORT_1, USART_BAUD_57600,USART_PARITY_NONE | USART_STOP_BITS_1 | USART_DATA_BITS_8);
  /* Redirect stdout to second port */
  rs232_redirect_stdout(RS232_PORT_1);
  clock_init();

  PRINTD("\n\nChecking MCUSR...\n");
  if(MCUSR & (1<<PORF )) PRINTD("Power-on reset.\n");
  if(MCUSR & (1<<EXTRF)) PRINTD("External reset!\n");
  if(MCUSR & (1<<BORF )) PRINTD("Brownout reset!\n");
  if(MCUSR & (1<<WDRF )) PRINTD("Watchdog reset!\n");
  if(MCUSR & (1<<JTRF )) PRINTD("JTAG reset!\n");
  MCUSR = 0;
  
  PRINTD("CLOCK_SECOND %d\n",CLOCK_SECOND);
  PRINTD("RTIMER_ARCH_SECOND %lu\n",RTIMER_ARCH_SECOND);
  PRINTD("F_CPU %lu\n",F_CPU);

#if STACKMONITOR
  /* Simple stack pointer highwater monitor. Checks for magic numbers in the main
   * loop. In conjuction with PERIODICPRINTS, never-used stack will be printed
   * every STACKMONITOR seconds.
   */
{
extern uint16_t __bss_end;
uint16_t p=(uint16_t)&__bss_end;
    do {
      *(uint16_t *)p = 0x4242;
      p+=10;
    } while (p<SP-10); //don't overwrite our own stack
}
#endif

/* Calibrate internal mcu clock against external 32768Hz watch crystal */
#define CONF_CALIBRATE_OSCCAL 0
#if CONF_CALIBRATE_OSCCAL
void calibrate_rc_osc_32k();
{
extern uint8_t osccal_calibrated;
uint8_t i;
  PRINTD("\nBefore calibration OSCCAL=%x\n",OSCCAL);
  for (i=0;i<10;i++) { 
    calibrate_rc_osc_32k();  
    PRINTD("Calibrated=%x\n",osccal_calibrated);
//#include <util/delay_basic.h>
//#define delay_us( us )   ( _delay_loop_2(1+(us*F_CPU)/4000000UL) ) 
//   delay_us(50000);
 }
   clock_init();
}
#endif 

  PRINTA("\n*******Booting %s*******\n",CONTIKI_VERSION_STRING);

/* rtimers needed for radio cycling */
  rtimer_init();

 /* Initialize process subsystem */
  process_init();

  /* etimers must be started before ctimer_init */
  process_start(&etimer_process, NULL);

#if RF230BB

  ctimer_init();
  /* Start radio and radio receive process */
  NETSTACK_RADIO.init();

/* Get a random seed for the 802.15.4 packet sequence number.
 * Some layers will ignore duplicates found in a history (e.g. Contikimac)
 * causing the initial packets to be ignored after a short-cycle restart.
 */
  random_init(rng_get_uint8());

  /* Set addresses BEFORE starting tcpip process */

  rimeaddr_t addr;
  if (params_get_eui64(addr.u8)) {
      PRINTA("Random EUI64 address generated\n");
  }
 
#if UIP_CONF_IPV6 
  memcpy(&uip_lladdr.addr, &addr.u8, sizeof(rimeaddr_t));
  rimeaddr_set_node_addr(&addr);  
  rf230_set_pan_addr(params_get_panid(),params_get_panaddr(),(uint8_t *)&addr.u8);
#elif WITH_NODE_ID
  node_id=get_panaddr_from_eeprom();
  addr.u8[1]=node_id&0xff;
  addr.u8[0]=(node_id&0xff00)>>8;
  PRINTA("Node ID from eeprom: %X\n",node_id);
  uint16_t inv_node_id=((node_id&0xff00)>>8)+((node_id&0xff)<<8); // change order of bytes for rf23x
  rimeaddr_set_node_addr(&addr);
  rf230_set_pan_addr(params_get_panid(),inv_node_id,NULL);
#else
  rimeaddr_set_node_addr(&addr);
  rf230_set_pan_addr(params_get_panid(),params_get_panaddr(),(uint8_t *)&addr.u8);
#endif
  rf230_set_channel(params_get_channel());
  rf230_set_txpower(params_get_txpower());

#if UIP_CONF_IPV6
  PRINTA("EUI-64 MAC: %x-%x-%x-%x-%x-%x-%x-%x\n",addr.u8[0],addr.u8[1],addr.u8[2],addr.u8[3],addr.u8[4],addr.u8[5],addr.u8[6],addr.u8[7]);
#else
  PRINTA("MAC address ");
  uint8_t i;
  for (i=sizeof(rimeaddr_t); i>0; i--){
    PRINTA("%x:",addr.u8[i-1]);
  }
  PRINTA("\n");
#endif

  /* Initialize stack protocols */
  queuebuf_init();
  NETSTACK_RDC.init();
  NETSTACK_MAC.init();
  NETSTACK_NETWORK.init();

#if ANNOUNCE_BOOT
  PRINTA("%s %s, channel %u , check rate %u Hz tx power %u\n",NETSTACK_MAC.name, NETSTACK_RDC.name, rf230_get_channel(),
    CLOCK_SECOND / (NETSTACK_RDC.channel_check_interval() == 0 ? 1:NETSTACK_RDC.channel_check_interval()),
    rf230_get_txpower());	   
#if UIP_CONF_IPV6_RPL
  PRINTA("RPL Enabled\n");
#endif
#if UIP_CONF_ROUTER
  PRINTA("Routing Enabled\n");
#endif
#endif /* ANNOUNCE_BOOT */

// rime_init(rime_udp_init(NULL));
// uip_router_register(&rimeroute);

  process_start(&tcpip_process, NULL);

#else /* !RF230BB */
/* Original RF230 combined mac/radio driver */
/* mac process must be started before tcpip process! */
  process_start(&mac_process, NULL);
  process_start(&tcpip_process, NULL);
#endif /* RF230BB */

#ifdef RAVEN_LCD_INTERFACE
  process_start(&raven_lcd_process, NULL);
#endif

  /* Autostart other processes */
  autostart_start(autostart_processes);

  /*---If using coffee file system create initial web content if necessary---*/
#if COFFEE_FILES
  int fa = cfs_open( "/index.html", CFS_READ);
  if (fa<0) {     //Make some default web content
    PRINTA("No index.html file found, creating upload.html!\n");
    PRINTA("Formatting FLASH file system for coffee...");
    cfs_coffee_format();
    PRINTA("Done!\n");
    fa = cfs_open( "/index.html", CFS_WRITE);
    int r = cfs_write(fa, &"It works!", 9);
    if (r<0) PRINTA("Can''t create /index.html!\n");
    cfs_close(fa);
//  fa = cfs_open("upload.html"), CFW_WRITE);
// <html><body><form action="upload.html" enctype="multipart/form-data" method="post"><input name="userfile" type="file" size="50" /><input value="Upload" type="submit" /></form></body></html>
  }
#endif /* COFFEE_FILES */

/* Add addresses for testing */
#if 0
{  
  uip_ip6addr_t ipaddr;
  uip_ip6addr(&ipaddr, 0xaaaa, 0, 0, 0, 0, 0, 0, 0);
  uip_ds6_addr_add(&ipaddr, 0, ADDR_AUTOCONF);
//  uip_ds6_prefix_add(&ipaddr,64,0);
}
#endif

/*--------------------------Announce the configuration---------------------*/
#if ANNOUNCE_BOOT
{
#if AVR_WEBSERVER
  uint8_t i;
  char buf1[40],buf[40];
  unsigned int size;

  for (i=0;i<UIP_DS6_ADDR_NB;i++) {
	if (uip_ds6_if.addr_list[i].isused) {	  
	   httpd_cgi_sprint_ip6(uip_ds6_if.addr_list[i].ipaddr,buf);
       PRINTA("IPv6 Address: %s\n",buf);
	}
  }
   cli();
   eeprom_read_block (buf1,eemem_server_name, sizeof(eemem_server_name));
   eeprom_read_block (buf,eemem_domain_name, sizeof(eemem_domain_name));
   sei();
   buf1[sizeof(eemem_server_name)]=0;
   PRINTA("%s",buf1);
   buf[sizeof(eemem_domain_name)]=0;
   size=httpd_fs_get_size();
#ifndef COFFEE_FILES
   PRINTA(".%s online with fixed %u byte web content\n",buf,size);
#elif COFFEE_FILES==1
   PRINTA(".%s online with static %u byte EEPROM file system\n",buf,size);
#elif COFFEE_FILES==2
   PRINTA(".%s online with dynamic %u KB EEPROM file system\n",buf,size>>10);
#elif COFFEE_FILES==3
   PRINTA(".%s online with static %u byte program memory file system\n",buf,size);
#elif COFFEE_FILES==4
   PRINTA(".%s online with dynamic %u KB program memory file system\n",buf,size>>10);
#endif /* COFFEE_FILES */

#else
   PRINTA("Online\n");
#endif /* AVR_WEBSERVER */

#endif /* ANNOUNCE_BOOT */
}
}

#if ROUTES && UIP_CONF_IPV6
static void
ipaddr_add(const uip_ipaddr_t *addr)
{
  uint16_t a;
  int8_t i, f;
  for(i = 0, f = 0; i < sizeof(uip_ipaddr_t); i += 2) {
    a = (addr->u8[i] << 8) + addr->u8[i + 1];
    if(a == 0 && f >= 0) {
      if(f++ == 0) PRINTF("::");
    } else {
      if(f > 0) {
        f = -1;
      } else if(i > 0) {
        PRINTF(":");
      }
      PRINTF("%x",a);
    }
  }
}
#endif

/*-------------------------------------------------------------------------*/
/*------------------------- Main Scheduler loop----------------------------*/
/*-------------------------------------------------------------------------*/
int
main(void)
{
#if UIP_CONF_IPV6
  uip_ds6_nbr_t *nbr;
#endif /* UIP_CONF_IPV6 */
  initialize();

  while(1) {
    process_run();
    watchdog_periodic();

#if 0
/* Various entry points for debugging in the AVR Studio simulator.
 * Set as next statement and step into the routine.
 */
    NETSTACK_RADIO.send(packetbuf_hdrptr(), 42);
    process_poll(&rf230_process);
    packetbuf_clear();
    len = rf230_read(packetbuf_dataptr(), PACKETBUF_SIZE);
    packetbuf_set_datalen(42);
    NETSTACK_RDC.input();
#endif

#if 0
/* Clock.c can trigger a periodic PLL calibration in the RF230BB driver.
 * This can show when that happens.
 */
    extern uint8_t rf230_calibrated;
    if (rf230_calibrated) {
      PRINTD("\nRF230 calibrated!\n");
      rf230_calibrated=0;
    }
#endif

/* Set DEBUGFLOWSIZE in contiki-conf.h to track path through MAC, RDC, and RADIO */
#if DEBUGFLOWSIZE
  if (debugflowsize) {
    debugflow[debugflowsize]=0;
    PRINTF("%s",debugflow);
    debugflowsize=0;
   }
#endif

#if PERIODICPRINTS
#if TESTRTIMER
/* Timeout can be increased up to 8 seconds maximum.
 * A one second cycle is convenient for triggering the various debug printouts.
 * The triggers are staggered to avoid printing everything at once.
 */
    if (rtimerflag) {
      rtimer_set(&rt, RTIMER_NOW()+ RTIMER_ARCH_SECOND*1UL, 1,(void *) rtimercycle, NULL);
      rtimerflag=0;
#else
  if (clocktime!=clock_seconds()) {
     clocktime=clock_seconds();
#endif

#if STAMPS
if ((clocktime%STAMPS)==0) {
#if ENERGEST_CONF_ON
#include "lib/print-stats.h"
  print_stats();
#elif RADIOSTATS
extern volatile unsigned long radioontime;
  PRINTF("%u(%u)s\n",clocktime,radioontime);
#else
  PRINTF("%us\n",clocktime);
#endif

}
#endif
#if TESTRTIMER
      clocktime+=1;
#endif

#if PINGS && UIP_CONF_IPV6
extern void raven_ping6(void); 
if ((clocktime%PINGS)==1) {
  PRINTF("**Ping\n");
  raven_ping6();
}
#endif

#if ROUTES && UIP_CONF_IPV6
if ((clocktime%ROUTES)==2) {
      
extern uip_ds6_netif_t uip_ds6_if;

  uint8_t i,j;
  PRINTF("\nAddresses [%u max]\n",UIP_DS6_ADDR_NB);
  for (i=0;i<UIP_DS6_ADDR_NB;i++) {
    if (uip_ds6_if.addr_list[i].isused) {
      ipaddr_add(&uip_ds6_if.addr_list[i].ipaddr);
      PRINTF("\n");
    }
  }
  PRINTF("\nNeighbors [%u max]\n",NBR_TABLE_MAX_NEIGHBORS);
  for(nbr = nbr_table_head(ds6_neighbors);
      nbr != NULL;
      nbr = nbr_table_next(ds6_neighbors, nbr)) {
    ipaddr_add(&nbr->ipaddr);
    PRINTF("\n");
    j=0;
  }
  if (j) PRINTF("  <none>");
  {
    uip_ds6_route_t *r;
    PRINTF("\nRoutes [%u max]\n",UIP_DS6_ROUTE_NB);
    j = 1;
    for(r = uip_ds6_route_head();
        r != NULL;
        r = uip_ds6_route_next(r)) {
      ipaddr_add(&r->ipaddr);
      PRINTF("/%u (via ", r->length);
      ipaddr_add(uip_ds6_route_nexthop(r));
       PRINTF(") %lus\n", r->state.lifetime);
      j = 0;
    }
  }
  if (j) PRINTF("  <none>");
  PRINTF("\n---------\n");
}
#endif

#if STACKMONITOR
if ((clocktime%STACKMONITOR)==3) {
  extern uint16_t __bss_end;
  uint16_t p=(uint16_t)&__bss_end;
  do {
    if (*(uint16_t *)p != 0x4242) {
      PRINTF("Never-used stack > %d bytes\n",p-(uint16_t)&__bss_end);
      break;
    }
    p+=10;
  } while (p<RAMEND-10);
}
#endif

    }
#endif /* PERIODICPRINTS */

#if RF230BB&&0
extern uint8_t rf230processflag;
    if (rf230processflag) {
      PRINTF("rf230p%d",rf230processflag);
      rf230processflag=0;
    }
#endif

#if RF230BB&&0
extern uint8_t rf230_interrupt_flag;
    if (rf230_interrupt_flag) {
 //   if (rf230_interrupt_flag!=11) {
        PRINTF("**RI%u",rf230_interrupt_flag);
 //   }
      rf230_interrupt_flag=0;
    }
#endif
  }
  return 0;
}

/*---------------------------------------------------------------------------*/

void log_message(char *m1, char *m2)
{
  PRINTF("%s%s\n", m1, m2);
}

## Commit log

2013-10-18 Added CC-BY-SA 3.0 license to schematic files
    Replaced the svn centric title border to a license centric one
    [roomunit-cpu-pwrclk.sch, roomunit-cpu.sch, roomunit-ethernet.sch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]
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2013-12-20 Simulation for roomunit power output filter
    [power_output_filter.sch]
2014-01-25 Replaced led-1.sym with led.sym from Kai-Martin Knaak
    [roomunit-poe-dcdc.sch]
2014-01-25 Changed to CC-BY-SA 4.0 for *.sch
    [roomunit-cpu-pwrclk.sch, roomunit-cpu.sch, roomunit-ethernet.sch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]
2014-01-25 Add printout number unused/missing in checkusedsyms.sh
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2014-09-05 Component values for DC/DC output filter simulated
    [power_output_filter.sch, roomunit-poe-dcdc.sch]
2014-09-08 DC/DC converter feedback loop calculations
    [roomunit-poe-dcdc.sch]
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2014-10-16 PoE dc-dc dcm components
    [roomunit-poe-dcdc.sch]
2014-10-16 DCM regulator feedback calculations
    [roomunit-psu.sch, roomunit.sch]
2014-10-17 DCM compensator. Stable with chosen values.
    [power_output_filter.sch, roomunit-poe-dcdc.sch]
2014-10-19 Report updates for DCM calculations
    [roomunit-psu.sch]
2014-10-20 New switching components in flyback. Input snubber added.
    [roomunit-poe-dcdc.sch, roomunit-psu.sch, roomunit-sensors.sch]
2014-10-21 Fixed bug in 12 V dc bias supply. Added parts numbers.
    12 V bias supply was connected backwards on flyback transformer.
    Components in DC/DC converter selected with parts numbers.
    [roomunit-poe-dcdc.sch, roomunit-psu.sch, roomunit-ui.sch]
2014-10-22 Start of revised power_output_filter.sch
    [power_output_filter.sch]
2014-10-22 Components chosen for ethernet and poe pages
    [roomunit-ethernet.sch, roomunit-poe-dcdc.sch, roomunit-psu.sch]
2014-10-22 Added note to add bridge rectifier for PoE
    [roomunit-ethernet.sch]
2014-10-23 New RJ45 connector, components for CPU, sensors and ethernet. Not complete.
    [roomunit-cpu.sch, roomunit-ethernet.sch, roomunit-psu.sch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]
2014-10-25 Updates to roomunit ethernet (signals) schem
    [roomunit-ethernet.sch]
2014-10-25 Added ESD protection for ethernet controller
    [roomunit-ethernet.sch]
2014-10-25 Component ordering numbers for roomunit CPU parts
    [roomunit-cpu-pwrclk.sch, roomunit-cpu.sch, roomunit-ethernet.sch]
2014-10-26 Components for roomunit UI/CPU
    [roomunit-cpu-pwrclk.sch, roomunit-ui.sch, roomunit.sch]
2014-10-28 Different PoE flyback transformer with matching components
    Adjusted input filter and snubber, sense resistor
    [roomunit-poe-dcdc.sch, roomunit-psu.sch]
2014-11-04 Changed PIR sensor, replaced temp/RH sensors.
    Replaced PIR subsystem board with onboard PIR sensor. Replaced
    discrete temperature and RH sensors with one integrated solution with
    better accuracy.
    [roomunit-sensors.sch, roomunit.sch]
2014-11-06 Components and footprints for roomunit
    [roomunit-poe-dcdc.sch, roomunit-sensors.sch, roomunit.sch]
2014-11-06 Changed display to EA-DOGM163 for prototyping
    [roomunit-ui.sch]
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2014-11-10 Adjusted flyback components, rearranged power circuits
    Another rectifying diode for the secondary side chosen.
    Added bulk capacitors for input and output filters, precis components
    to be chosen at later point.
    Rearranged power schematics for possibly breaking off into secondary
    power board.
    [roomunit-poe-dcdc.sch, roomunit-psu.sch, roomunit.sch]
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2014-11-17 Added extra bulk input/output capacitors to roomunit dc/dc
    [roomunit-poe-dcdc.sch]
2014-11-19 Fixed diode polarity bug.
    [roomunit-poe-dcdc.sch, roomunit-psu.sch]
2014-11-19 Unused symbol cleanup
    [power_output_filter.sch]
2014-11-20 Added footprints
    One more to be created for Lumberg DC jack.
    [roomunit-cpu-pwrclk.sch, roomunit-cpu.sch, roomunit-ethernet.sch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]
2014-11-21 Footprint for Lumberg DC connector, changed sym to match
    [roomunit-psu.sch]
2014-11-22 Footprint for MCDTS2 switches
    [roomunit-ui.sch]
2014-11-30 PCB for roomunit. Fixed some symbols and footprints.
    Changed pin names of elyctrolytic capacitors
    Added silk outline for wall box
    Symbol with correct pinnumbers for IRLML0100
    [roomunit-poe-dcdc.sch]
2014-11-30 Removed redundant jumper
    [roomunit-ui.sch]
2014-11-30 Fixed wrong footprint for U300 smt crystal
    Changed unpolarized capacitor pinout
    Added git ignores
    [roomunit-cpu-pwrclk.sch, roomunit-ethernet.sch, roomunit-poe-dcdc.sch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]
2014-11-30 Breakout of roomunit into three PCBs
    Main functionality card
    Daughter card for display
    Daughter card for DC/DC converter
    [roomunit-display-daughter.sch, roomunit-psu.sch, roomunit-ui.sch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]
2014-11-30 Renamed breakout of roomunit PSU schematics
    [roomunit-psu-daughter.sch]
2014-11-30 Cleaned up schematic
    [roomunit-cpu.sch, roomunit-psu-daughter.sch, roomunit.sch]
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2014-12-01 First draft roomunit PSU PCB daughterboard.
    Headers connecting to roomunit motherboard tilted 5 degrees
    respectively to avoid connecting upside down.
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2014-12-01 Added symbols for accessories (switchcaps, jumpers, receptacles)
    [roomunit-display-daughter.sch, roomunit-ui.sch, roomunit.sch]
2014-12-02 Moved a few components around, DC connector+plug will not fit
    Currently selected 48 VDC connector from Lumberg will not fit
    together with the ethernet connector inside the wall box.
    Another option, perhaps a lower connector that will fit on top side
    of main board between casing and PCB, will have to be investigated.
    [roomunit-psu-daughter.sch]
2014-12-02 Outline for display board. Fixed exterior components.
    Buttons and PIR sensor moved to currently suggested positions.
2014-12-06 Moved DC socket to main board (sch), adjusted psu header connectors (pcb)
    Changed to simple angled pin connector due to space issues
    [roomunit-psu-daughter.sch, roomunit.sch]
2014-12-17 Roomunit PSU PCB
    Power and signal routing on DC/DC OK
    DRC checks are clear, footprints adjusted accordingly
2014-12-18 DRC/ERC fixes for roomunit-display.pcb
2015-01-10 Added DC/DC input filter inductor
    [roomunit-poe-dcdc.sch, roomunit.sch]
2015-01-13 Some PCB rework for DC/DC input filter
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2015-01-13 Changed polygon clearance for 1005m footprints
    Avoids slivers between footprint terminals for 1005m footprints
2015-01-13 Changed DC input filter inductor size
    Larger footprint to match filter currents
    [roomunit-poe-dcdc.sch]
2015-02-01 Roomunit PSU PCB changes: clearances, thermals
    Moved secondary top GND plane in toward center to cover more of
    secondary voltage components. Increased clearances between primary and
    secondary ground planes/traces. Made non-solder vias fully connected
    with their planes instead of thermal traces.
2015-02-01 Added JTAG and USART connectors for roomunit
    [roomunit.sch]
2015-02-24 Moved connector on EA display board for more space
    Display board onnector will touch ethernet connector on roomunit main
    board at previous location.
2015-02-25 Added EMI reducing Y-capacitors to roomunit-psu
    [roomunit-poe-dcdc.sch, roomunit-psu-daughter.sch]
2015-02-27 Changed roomunit-psu board outline, moved silk text
    Added board rev text in bottom copper
2015-02-28 Component arrangement on roomunit main pcb
    [roomunit-ethernet.sch]
2015-03-01 Added filter on Ethernet analog VDD, more routing
    [roomunit-ethernet.sch]
2015-03-20 More roomunit PCB routing
    Analog Ethernet ground planes
    Digital Ethernet signals to MCU
2015-03-21 Added ground floods and some VDD traces
    Several DRC errors introduced, needs fixing
2015-03-22 Fixed clearance for 1005m footprint. Roomunit routing.
2015-03-24 Roomunit mainboard PCB finished routing.
    All nets connected, no DRC error
2015-03-25 Fixed drill holes for roomunit mainboard to standard sizes
    Made CONN300 visible
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2015-03-29 Added hiccup limiting resistor for DC/DC bias
    [roomunit-poe-dcdc.sch]
2015-03-29 Changed PoE controller TPS23757->TPS23754
    New controller has thermal padded package, needing rearrangement
    of roomunit-psu PCB.
    [roomunit-poe-dcdc.sch, roomunit-psu-daughter.sch]
2015-03-30 Small fixups of copper floods and trace routings roomunit
2015-03-31 Added mounting screw for roomunit casing
    [roomunit.sch]
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2015-04-06 Changed solder mask clearance for roomunit mainboard
    Added holes to unplated slots, Excellon drill file needs fixup after
    gerber export by moving drills to plated slot route file.
2015-04-07 Fixed wrongly assigned footprint for TLV431 component
    [roomunit-poe-dcdc.sch]
2015-06-11 Fixed footprint 3528m, added capacitor version
    Fixed one resistor order number in roomunit-psu
    [roomunit-poe-dcdc.sch]
2015-06-11 Gerbers, drill files and PNG as ordered 2015-06-11
    [roomunit-display-midas.GBL, roomunit-display-midas.GBO, roomunit-display-midas.GBS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]
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
